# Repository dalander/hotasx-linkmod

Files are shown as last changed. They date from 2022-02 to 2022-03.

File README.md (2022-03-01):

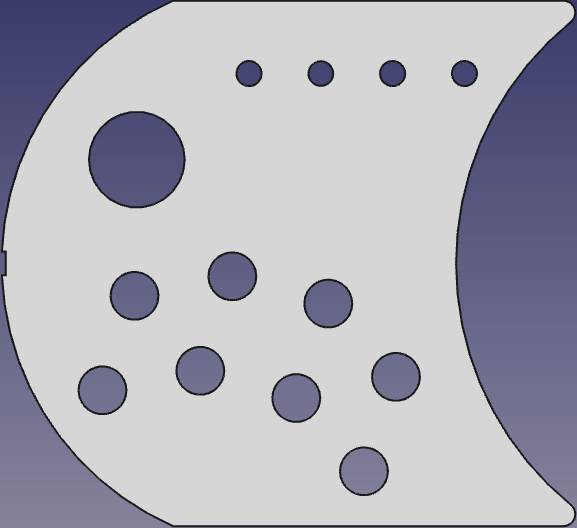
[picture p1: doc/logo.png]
HotasX-Linkmod


# hotasx-linkmod 

# Table of contents

- [hotasx-linkmod !ESPBuildBadge](#hotasx-linkmod-)
- [Table of contents](#table-of-contents)
  - [Description/Beschreibung](#descriptionbeschreibung)
  - [What is it](#what-is-it)
    - [Features](#features)
  - [Hardware](#hardware)
    - [3DFiles](#3dfiles)
    - [Wiring](#wiring)
  - [Software](#software)
- [Environment](#environment)

## Description/Beschreibung

## What is it

This project is an extension to the Thrustmaster HotasX Joystick. As this joystick can connect the thrust module to the joystick everyone has as first the idea to build a link in between. There are allready some projects on thingiverse, but as I wanted to learn a bit, this project started. 
It contains the Freecad files for the case, as well as the STL files. Feel free to mod it to your belongings. Would appreciate, if you change something, to send an info to me what and how. Since there are many ideas about the top cover design, I could merge them into this repository, link to your repo or maye we can make a branch here for the mod mod.

Update: The linkmod is in use with elite dangerous and working as expected! Yes, I finished a project, such a good feeling.

### Features

* Connectable without screws
* Open and close wihtout screws (clippable)
* place for small powerbank
* hole for external powerbank or direct usb connection
* Bluetooth gamepad HID device
* 2 axis Joystick
* 8 Button
* 4 Switches (layout is button / off / switch)

Some pictures to give an idea

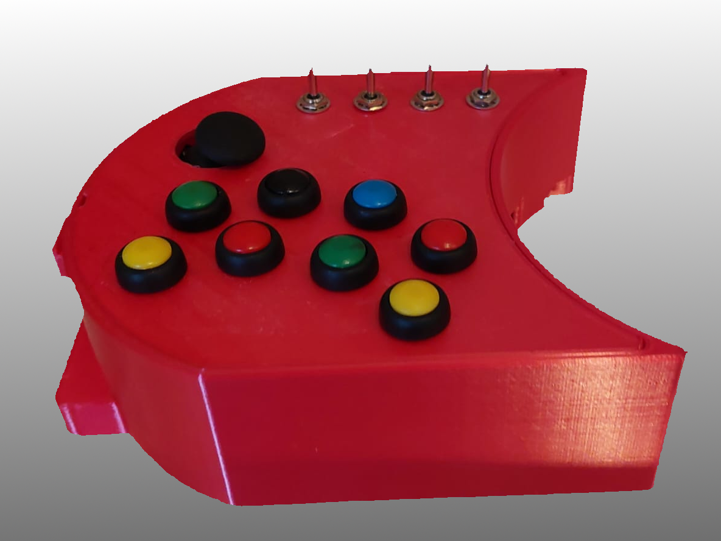
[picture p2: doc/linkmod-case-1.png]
HotasX-Linkmod-Case1

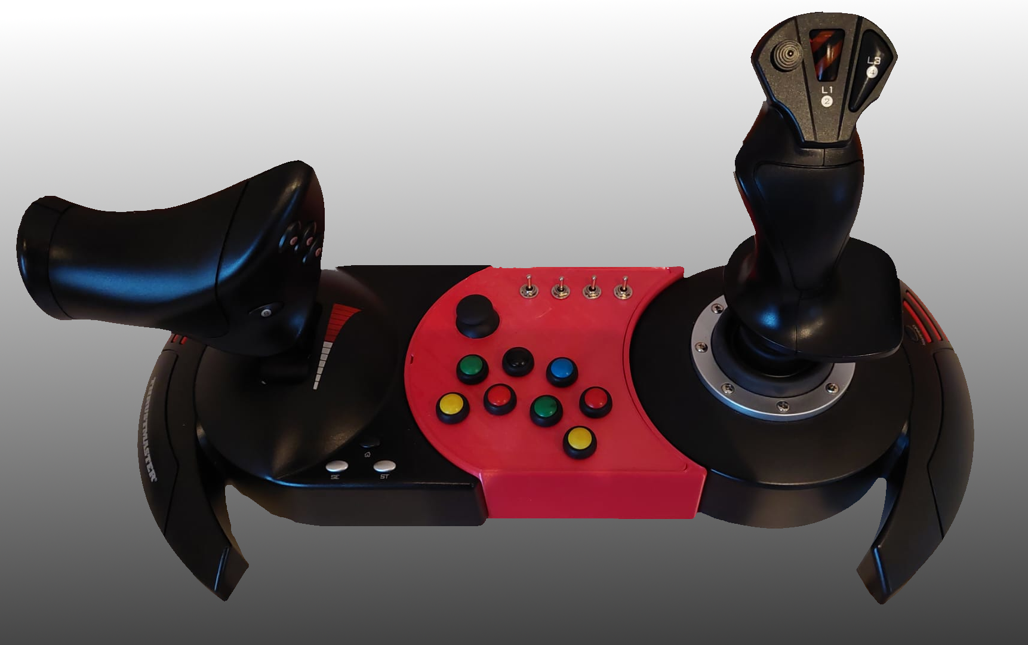
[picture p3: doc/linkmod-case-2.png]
HotasX-Linkmod-Case2

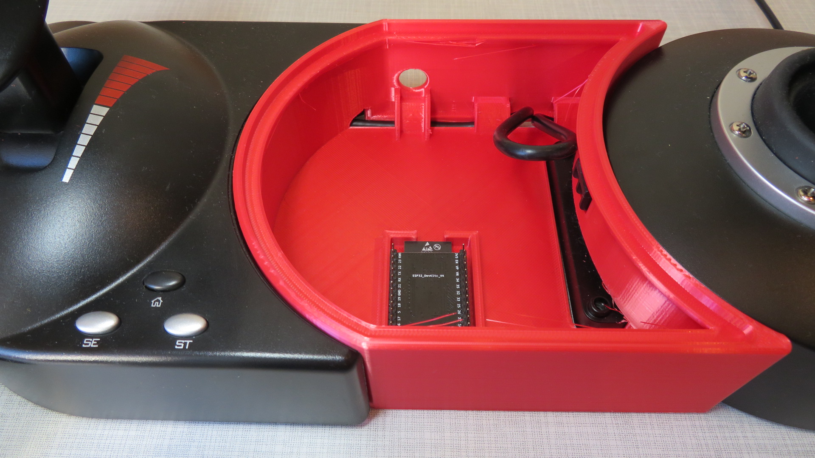
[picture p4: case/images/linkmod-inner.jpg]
HotasX-Linkmod-Case4


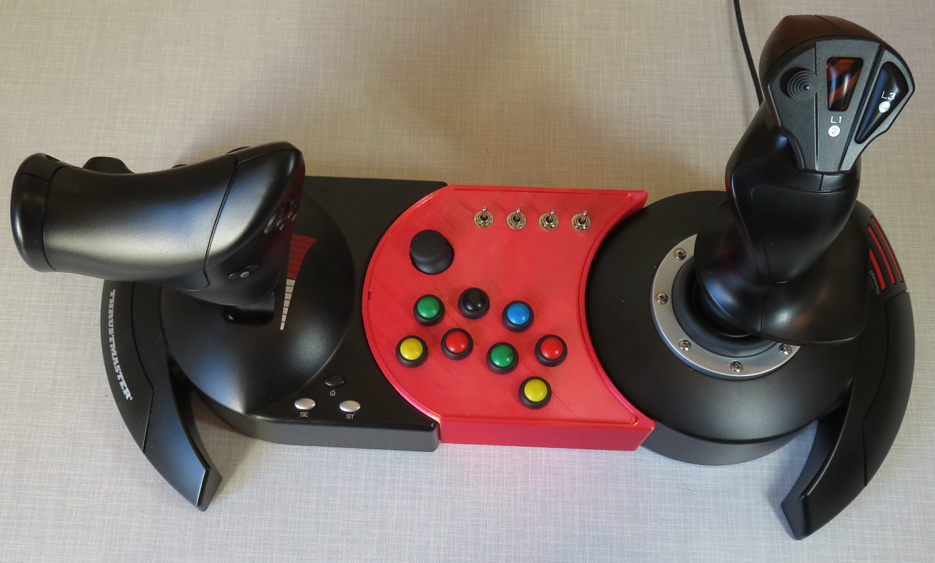
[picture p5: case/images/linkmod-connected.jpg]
HotasX-Linkmod-Case3

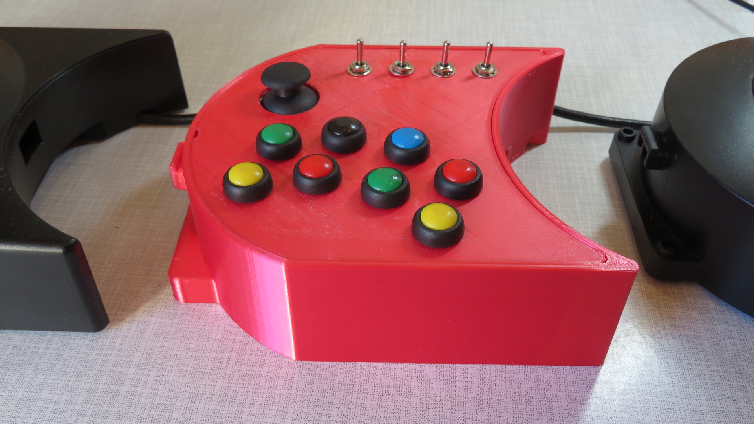
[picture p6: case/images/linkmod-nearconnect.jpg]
HotasX-Linkmod-Case5

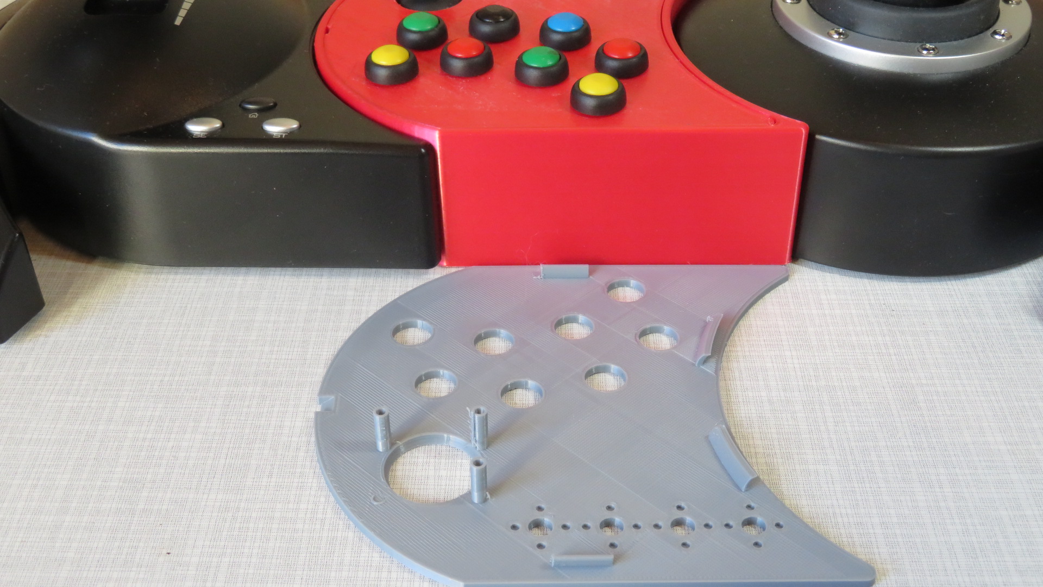
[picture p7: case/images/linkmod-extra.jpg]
HotasX-Linkmod-Case6


## Hardware

* ESP32 "Dev Kit" (az-delivery-devkit-v4) Why? I allready had one left from another project, and didnt want to buy another controller. As most others are using an Arduino Micro Pro I would suggest that you take a look on that one, too.
* Thrustmaster Hotas X (which I got as present on XMas). Throttle and Joystick can be attached together, thats why everyone has instant the idea to print something in between with a 3D printer
* Switches MTS-213-A1 -> This switches have one direction switched, the other direction is like a button. This would help if the switch isnt synced with the game anymore.
* Buttons (sorry for link into a shop, isnt an afiliate link) like https://www.pollin.de/p/drucktaster-rot-oe-17-5mm-36v-1a-1-polig-schliesser-loetanschluss-421052 This buttons have a good haptic when pressing, remembers a bit to a cherry keyboard.
* JOY-IT Joystick Module
* and of course, as you whish to attach, the Hotas X itself.

### 3DFiles

Take a look into [Freecad and STL Folders for the case files](case)

### Wiring



## Software

Using VSCode with installed Platform IO Extension for development.
PlatformIO supports the Arduino Framework which makes it more easy to access allready supported devices.

* https://code.visualstudio.com/
* https://platformio.org/
  
# Environment 

Please use https://platformio.org/ or https://docs.platformio.org/en/latest/projectconf/index.html for detailed descriptions. For this project so far just the info, that it will have multiple environments configured, depending for developer and connection. In platformio.ini the root section [env] configures all default parts of environments. In the sections like [env:hugin] the specialized settings are configured. This makes it more easy to switch between different serial ports, but change common parts in [env].

[Some hints how to build are here](doc/Build.md)

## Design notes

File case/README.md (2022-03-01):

# hotasx-linkmod Printing

In current version the screw Connectors and the clip hooks of the cover are improved. Rounded edges gives more stability.
Printed good on an Ender 3 V2. 
in freecad you can find the source files, if you just interested to print, choose the stl folder to download.
Any critic, improvement suggestion is welcome. This is my second freecad work, would apreciate to get more input from you.

At this point many thanks to flowwies channel!
https://www.youtube.com/channel/UCyGwIx_PzM_zE3FKhZRbygQ

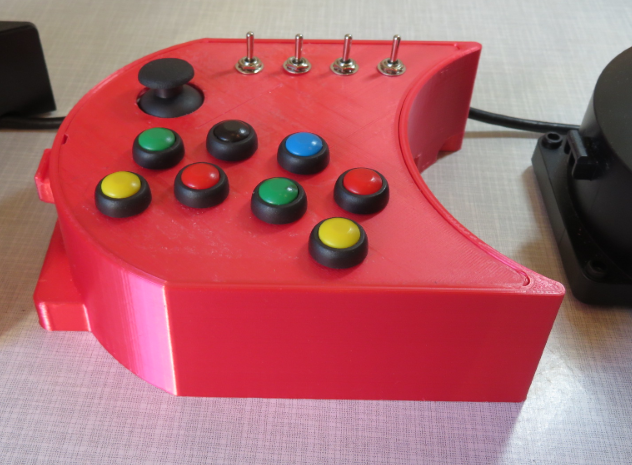
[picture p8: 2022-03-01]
case/images/linkmod-nearconnect (Klein).png

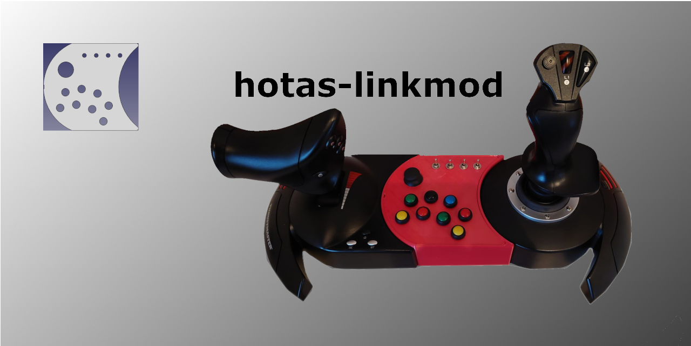
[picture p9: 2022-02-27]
doc/socialpreview.png

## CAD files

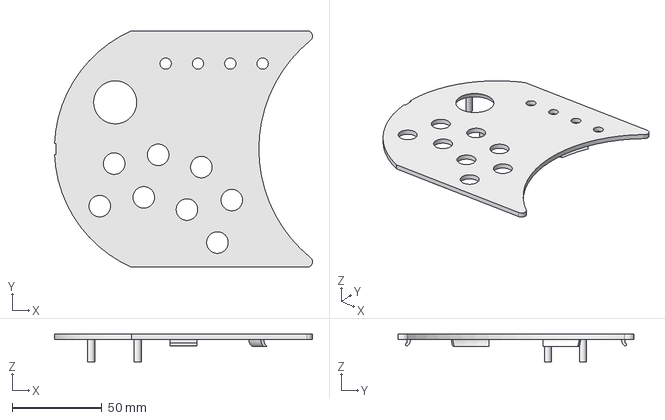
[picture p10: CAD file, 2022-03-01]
case/freecad/HotasExtension-V2-cover.FCStd
143.7 x 131.7 x 15.5 mm

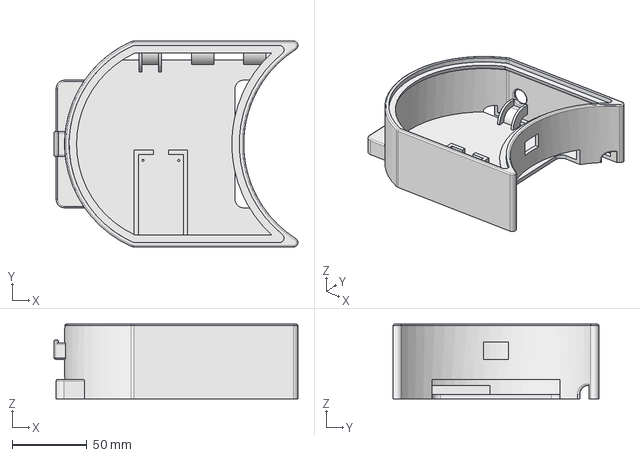
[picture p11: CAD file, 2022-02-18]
case/freecad/HotasExtension-V2.FCStd
163.5 x 137.9 x 50.0 mm

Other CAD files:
case/stl/HotasExtension-V2-cover.stl
case/stl/HotasExtension-V2.stl

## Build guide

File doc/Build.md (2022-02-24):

HotasX-Linkmod

# hotasx-linkmod 

## Howto Build the Project

After cloning the repository you can open the platformio-project folder as a project:

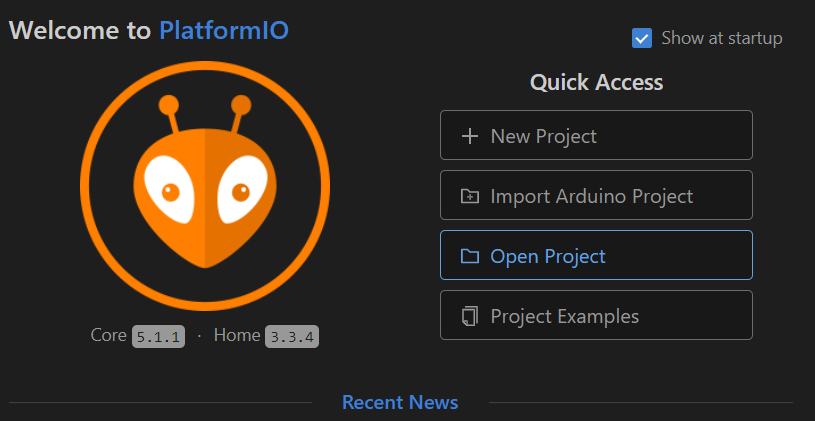
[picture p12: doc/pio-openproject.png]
PIO Open Project

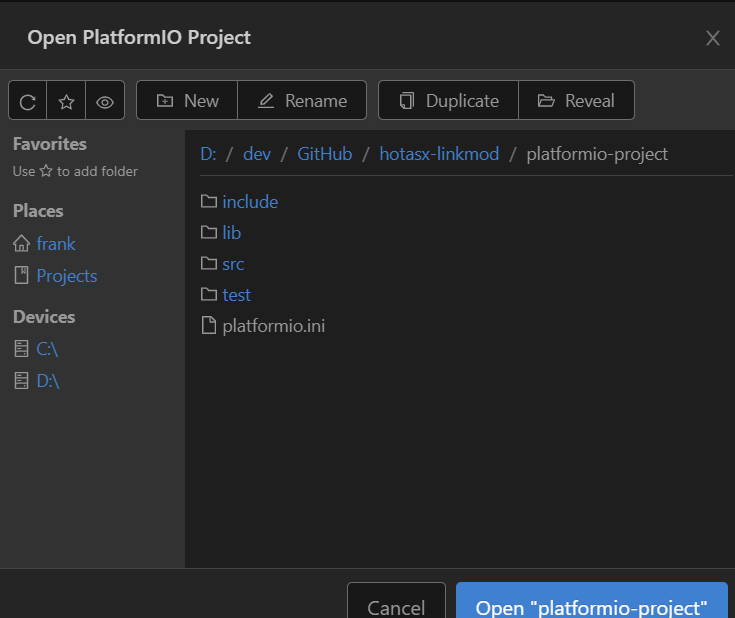
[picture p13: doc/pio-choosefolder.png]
PIO Choose Folder


Once the project opened one way to use Platform IO environment is using the taskbar:
PIO Taskbar

Right from the GIT symbols the Platform IO Icons are shown.
* House: Go to PlatformIO home (opening projects, search libraries etc)
* Checkmark: Compile current project using selected Environment 
* Arrow: Compile current project and upload to ESP using selected Environment  
* Trashcan: Clean current Project
* Connector Plug: Show ESP Serial Monitor interface
* Square: Open Terminal (less used)
* Folder Symbol with env:environmentname: Select active environment (upload via COMx ... )

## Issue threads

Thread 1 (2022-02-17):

Save Joystick callibration persistent

dalander, 2022-02-17:
After first calibration the highes and lowest value should not change anymore.
Once it is reached, it can be stored into NVRAM (or however) so the reinit every startup is not needed.
Remark: Probably a reset function should be implemented, for changing the stick if broken.

dalander, 2022-02-19:
Added with 857712476a66a722191322572506542f1c35ff1a

Closed 2022-02-19.

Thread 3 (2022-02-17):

Add Freecad and STL Files

dalander, 2022-02-17:
The surrounding Box is important, it should be here.
But currently the design wasnt printed successfully in 100% Version. And dont want to upload not working files as it costs material to print.

dalander, 2022-02-18:
Added first version of files

Closed 2022-02-18.

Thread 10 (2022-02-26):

Adding Rotary Encoder functionality into ESP32 Code

dalander, 2022-02-26:
Got the idea from reddit to include rotary encoder functionality.
This needs to be checked how it could be supported by games.
Currently two options are an idea:
* Each rotation up presses button A, rotation down presses B -> Could be used for toggeling radar modes or similar
* Rotation up and down is added or substracted to an analog axis value. This would probably need a reset possibility, too

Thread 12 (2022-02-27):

Joystick Button not workin

dalander, 2022-02-27:
After connecting all wires i changed input to input_pullup.
Unfortunatly Joystick Button is not working. Maybe a Wiring issue, but needs to be checked.

dalander, 2022-02-28:
Hardware defect, joystick broken

Closed 2022-02-28.

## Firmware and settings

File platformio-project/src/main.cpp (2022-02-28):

/*
 * main.cpp
 * This is a Hotas X Linkmod firmware. 
 * Planned Features are 
 *  8 BUttons
 *  4 Switches 
 *  minijoystick with separate pushbutton
 * 
 * I tried to keep this file simple as possible, straight forward. There is no goal to write a 
 * new library or to make it better than another one.
 * There are 3 goals: 
 *  get my linkmod running
 *  share it as template or inspiration for other, who are not able to code in complex classes
 *  Have fun with it...
 *  
 *  Created on: Februar 2022
 *      Author: Frank Weichert
 */

#include <Arduino.h>
#include <BleGamepad.h> 
#include <main.h>
#include <EEPROM.h>

//Remove // to activate debugging mode 
//#define DEBUG
//#define DEBUG2

BleGamepad *bleGamepad;
///  \def DEADZONE defines the range where joystick does not react
#define DEADZONE 100
///  \def MAXBUTTON defines the maximum number of used buttons (including switches)
#define MAXBUTTON 13
/// 13 Bytes in EEPROM, 6 int16_t and one byte check initialized status
#define EEPROMSIZE 14

///  \def SWAP_X_AXIS 1 -> Axis will be swapped, 0 -> Axis will be left like it is
#define SWAP_X_AXIS 1
///  \def SWAP_Y_AXIS 1 -> Axis will be swapped, 0 -> Axis will be left like it is
#define SWAP_Y_AXIS 1


/// defenition of the physical gpio buttonpins that are used 
const int buttonPins[]  = {
                            /*BUTTONS*/   23,22,21,19,18,5,17,16
                            /*SWITCHES*/  ,4,2,15,33
                            /*JOYBUTTON*/ ,32
                            }; 

int buttonPreviousValue[MAXBUTTON]; //!< internal use to detect edges

/// index of buttonpins matches the corrosponding BUTTON_ here 
const int buttonMap[] =  {
                            /*BUTTONS*/   BUTTON_1,BUTTON_2,BUTTON_3,BUTTON_4,BUTTON_5,BUTTON_6,BUTTON_7,BUTTON_8
                            /*SWITCHES*/  ,BUTTON_9,BUTTON_10,BUTTON_11,BUTTON_12
                            }; 

const int xAxisPin = 34; //!< GPIO for x Axis
const int yAxisPin = 35; //!< GPIO for y Axis

int16_t eepromUpdateLoopCounter = 0;  //!< Do not update every loop to save eeprom lifetime

// Used for autocalibration 
struct JCalibrationData {
  byte isInitialized = 1; //!< Determines if EEPROM has been used before
  byte dirtyFlag = 0;   //!< EEPROM write should only update not changed values, but to be sure we will only write if we detect changes, too.
  int16_t xMid =  0;  //!< x Mid Position taken from Start or NVRam
  int16_t yMid =  0;  //!< y Mid Position taken from Start or NVRam
  int16_t xLow =  0;  //!< x lowest Position determined during moving or at Start from NVRam
  int16_t yLow =  0;  //!< y lowest Position determined during moving or at Start from NVRam
  int16_t xHigh=  0;  //!< x highest Position determined during moving or at Start from NVRam
  int16_t yHigh=  0;  //!< y highest Position determined during moving or at Start from NVRam
} ;

JCalibrationData joyWorkData;

// variable for storing the mapped potentiometer value
int16_t xAxisValue = 0; //!< mapped x Axis value to BLE HID Range (-32767 - +32768)
int16_t yAxisValue = 0; //!< mapped y Axis value to BLE HID Range (-32767 - +32768)

int16_t xAxisPreviousValue = 0; //!< mapped x Axis value to BLE HID Range (-32767 - +32768) of previous loop
int16_t yAxisPreviousValue = 0; //!< mapped y Axis value to BLE HID Range (-32767 - +32768) of previous loop

int16_t joyxAxisValue =  0; //!< real Joystick analog input (0-4095) for x Axis
int16_t joyyAxisValue =  0; //!< real Joystick analog input (0-4095) for y Axis

void setup() {

  #ifdef DEBUG 
  Serial.begin(115200);
  Serial.println("HotasLinkmod starting.");
  #endif

  bleGamepad = new BleGamepad("HotasLinkmod","FWE",100);

  // Cleanup
  memset(buttonPreviousValue,0,MAXBUTTON*sizeof(int));
  
  EEPROM.begin(EEPROMSIZE);

  // Init Buttonpullups
  for (int buttonIndex=0;buttonIndex<MAXBUTTON;buttonIndex++){
      pinMode(buttonPins[buttonIndex],INPUT_PULLUP);
  }

  joyWorkData.xMid = analogRead(xAxisPin);
  joyWorkData.yMid = analogRead(yAxisPin);

  // If started with full tilted Joystick we take it as a re init whish
  if (joyWorkData.xMid == 0 || joyWorkData.yMid==0){
    clearNVRAM();
  }
  
  // Read calibration DAta from NVRam
  readNVRAM();

  // thanks lemmingdev for this library
  bleGamepad->begin(MAXBUTTON, 0,true, true,false, false, false, false, false,false, false, false, false, false, false);
}

void loop() {
  eepromUpdateLoopCounter++;
  joyxAxisValue =  analogRead(xAxisPin);
  joyyAxisValue =  analogRead(yAxisPin);
  
  // Continuesly meassure boundaries
  updateCalibration();

  // Strange looking mapping, but as ADC is 0-4095 and the mid position is not 2047 this should ensure
  // that the mid position is really centered. The remaining values 
  if (joyxAxisValue < joyWorkData.xMid)
        xAxisValue = map ( joyxAxisValue,joyWorkData.xLow,joyWorkData.xMid,-32760,0);

  if (joyxAxisValue >= joyWorkData.xMid)
        xAxisValue = map ( joyxAxisValue,joyWorkData.xMid,joyWorkData.xHigh,0,32760);

  if (joyyAxisValue < joyWorkData.xMid)
        yAxisValue = map ( joyyAxisValue,joyWorkData.yLow,joyWorkData.yMid,-32760,0);

  if (joyyAxisValue >= joyWorkData.xMid)
        yAxisValue = map ( joyyAxisValue,joyWorkData.yMid,joyWorkData.yHigh,0,32760);



  if(bleGamepad->isConnected()) {
    // Detect all Button States 
    for (int buttonIndex=0;buttonIndex<MAXBUTTON;buttonIndex++){
      int currentEdge = detectEdge(buttonIndex);
      switch (currentEdge){
          case -1:
          bleGamepad->release(buttonMap[buttonIndex]);
          break;
        case 0:
          break;
        case 1:
          bleGamepad->press(buttonMap[buttonIndex]);
          break;
      }
    }

    #ifdef DEBUG2
    Serial.printf("Current Workdata\nisInitialized\t=\t%d\ndirtyFlag\t=\t%d\nxHigh\t=\t%d\nxLow\t=\t%d\nxMid\t=\t%d\nyHigh\t=\t%d\nyLow\t=\t%d\nyMid\t=\t%d\n",
      joyWorkData.isInitialized,
      joyWorkData.dirtyFlag,      
      joyWorkData.xHigh,
      joyWorkData.xLow,
      joyWorkData.xMid,
      joyWorkData.yHigh,
      joyWorkData.yLow,
      joyWorkData.yMid);
      Serial.printf("PIN %3d has value %3d->Mapped(%d)\n" ,xAxisPin,joyxAxisValue,xAxisValue);
      Serial.printf("PIN %3d has value %3d->Mapped(%d)\n\n" ,yAxisPin,joyyAxisValue, yAxisValue);
    #endif

    // Swap axis directrions if needed
    if (SWAP_X_AXIS == 1){
      xAxisValue *=-1;
    }

    if (SWAP_Y_AXIS == 1){
      yAxisValue *=-1;
    }

    // Only send if something has been changed. Maybe it saves a bit transmission.
    if ((xAxisValue != xAxisPreviousValue) || yAxisValue != yAxisPreviousValue) { 
      bleGamepad->setAxes(xAxisValue,yAxisValue,0, 0,0, 0,0, 0, DPAD_CENTERED);
      xAxisPreviousValue=xAxisValue;
      yAxisPreviousValue=yAxisValue;
    }

    #ifdef DEBUG2
      delay(1000);
    #endif
  }
}

int16_t respectDeadZone(int16_t value){
  if (abs(value) < DEADZONE)
  {
    return 0;
  }
  return value;
}

int detectEdge(int buttonIndex){
  int currentValue = digitalRead(buttonPins[buttonIndex]);  
  // Shift input for pullup
  currentValue = currentValue==1 ? 0 : 1;

  #ifdef DEBUG2
    Serial.printf("PIN=%3d: Index=%3d  with prev=%3d , now=%3d   \n",buttonPins[buttonIndex] ,buttonIndex ,buttonPreviousValue[buttonIndex],currentValue);
  #endif
  if (currentValue > 0){
    // Detect if raising
    if ( buttonPreviousValue[buttonIndex] > 0){
      return 0; // no edge
    }else{
      buttonPreviousValue[buttonIndex] = currentValue;
      return 1; // positive edge
    }
  }else{
    //detect if falling
        if ( buttonPreviousValue[buttonIndex] <= 0){
      return 0; // no edge
    }else{
      buttonPreviousValue[buttonIndex] = currentValue;
      return -1; // negative edge
    }
  }
}

void readNVRAM(){
  byte isInitialized = EEPROM.read(0); 
  #ifdef DEBUG
    Serial.printf("EEProm Initializer is=%d (255=unitialized)\n",isInitialized);
  #endif

  if (isInitialized == 0xFF)
  {
    //Uninitialized, start here
    // Hope that system is started without tilted joystick to determine mid position
    EEPROM.put(0,joyWorkData);
    #ifdef DEBUG
      Serial.printf("Initialized EEPROM with values\nisInitialized\t=\t%d\ndirtyFlag\t=\t%d\nxHigh\t=\t%d\nxLow\t=\t%d\nxMid\t=\t%d\nyHigh\t=\t%d\nyLow\t=\t%d\nyMid\t=\t%d\n",
      joyWorkData.isInitialized,
      joyWorkData.dirtyFlag,
      joyWorkData.xHigh,
      joyWorkData.xLow,
      joyWorkData.xMid,
      joyWorkData.yHigh,
      joyWorkData.yLow,
      joyWorkData.yMid);
    #endif
  }else{
    EEPROM.get(0,joyWorkData);
    #ifdef DEBUG
      Serial.printf("Read EEPROM Data values\nisInitialized\t=\t%d\ndirtyFlag\t=\t%d\nxHigh\t=\t%d\nxLow\t=\t%d\nxMid\t=\t%d\nyHigh\t=\t%d\nyLow\t=\t%d\nyMid\t=\t%d\n",
        joyWorkData.isInitialized,
        joyWorkData.dirtyFlag,
        joyWorkData.xHigh,
        joyWorkData.xLow,
        joyWorkData.xMid,
        joyWorkData.yHigh,
        joyWorkData.yLow,
        joyWorkData.yMid);
    #endif
  }
}

void updateCalibration(){
  // Continuesly meassure boundaries
  if (joyxAxisValue < joyWorkData.xLow)   {
    joyWorkData.xLow  = joyxAxisValue;
    joyWorkData.dirtyFlag=true;
  }
  if (joyxAxisValue > joyWorkData.xHigh){
      joyWorkData.xHigh = joyxAxisValue;
      joyWorkData.dirtyFlag=true;
  }
  if (joyyAxisValue < joyWorkData.yLow){
      joyWorkData.yLow  = joyyAxisValue;
      joyWorkData.dirtyFlag=true;
  }
  if (joyyAxisValue > joyWorkData.yHigh){
      joyWorkData.yHigh = joyyAxisValue;
      joyWorkData.dirtyFlag=true;
  }

  if (eepromUpdateLoopCounter%10000==0 && joyWorkData.dirtyFlag){
    joyWorkData.dirtyFlag=false;
    EEPROM.put(0,joyWorkData);
    #ifdef DEBUG
      Serial.printf("Save EEPROM @loop = %d with new values\nisInitialized\t=\t%d\ndirtyFlag\t=\t%d\nxHigh\t=\t%d\nxLow\t=\t%d\nxMid\t=\t%d\nyHigh\t=\t%d\nyLow\t=\t%d\nyMid\t=\t%d\n",
        eepromUpdateLoopCounter,
        joyWorkData.isInitialized,
        joyWorkData.dirtyFlag,
        joyWorkData.xHigh,
        joyWorkData.xLow,
        joyWorkData.xMid,
        joyWorkData.yHigh,
        joyWorkData.yLow,
        joyWorkData.yMid);
    #endif
    EEPROM.commit();
  }
}

void clearNVRAM(){
  #ifdef DEBUG
    Serial.printf("Cleanup NVRAM, restart to initialize again.\n");
  #endif 
  joyWorkData.isInitialized = 0xFF;
  joyWorkData.dirtyFlag     = 0;
  joyWorkData.xHigh         = 0;
  joyWorkData.xLow          = 0;
  joyWorkData.xMid          = 0;
  joyWorkData.yHigh         = 0;
  joyWorkData.yLow          = 0;
  joyWorkData.yMid          = 0;

  EEPROM.put(0,joyWorkData);
  EEPROM.commit();

  while(1){
    #ifdef DEBUG
      Serial.printf("Cleaned up NVRAM, waiting for restart.\n");
    #endif
    delay(5000);
  }
}

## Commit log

2022-02-18 Mixed ButtonPins again
2022-02-18 Added 3d Files
    [HotasExtension-V2-cover.FCStd, HotasExtension-V2-cover.stl, HotasExtension-V2.FCStd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]
2022-02-19 Added Joystick Calibration added photos, extended readme fixed axis swap Calibration forced if one axis is zero at start
    [main.cpp]
2022-02-20 Wiring added
2022-02-26 Skrewmount and Hooks strengthened
    [HotasExtension-V2-cover-untested.stl, HotasExtension-V2-cover.FCStd]
2022-02-27 After real print test changed tested stl
    [HotasExtension-V2-cover-untested.stl, HotasExtension-V2-cover.stl]
2022-02-27 Readme case
2022-02-27 Input Pullup set because all wired pins were too noisy Joystick Button not working
    [main.cpp]
2022-03-01 fixed type, thanks u/Dee_Jiensai
    [HotasExtension-V2-cover.FCStd]
